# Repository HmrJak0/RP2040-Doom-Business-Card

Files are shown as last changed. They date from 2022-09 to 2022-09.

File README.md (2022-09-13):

# RP2040 Stamp Footprints and Symbols

This repo contains symbols and footprints for the RP2040 Stamp for various CAD programs.

The "KiCad" directory can be used with KiCad v6, for v5 version, see the "KiCad5" directory.

If you notice any issues with the footprints (we are mainly KiCad users), or want to port the footprint to a new program, PRs are very welcome :)

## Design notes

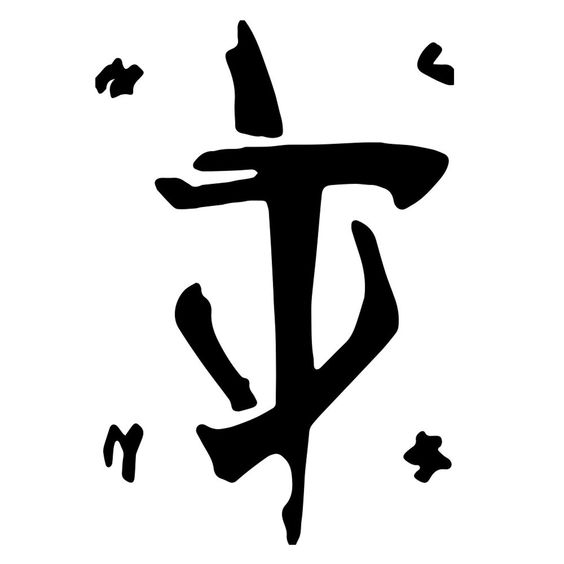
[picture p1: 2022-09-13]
Doom_Slayer_Sigil.jpg

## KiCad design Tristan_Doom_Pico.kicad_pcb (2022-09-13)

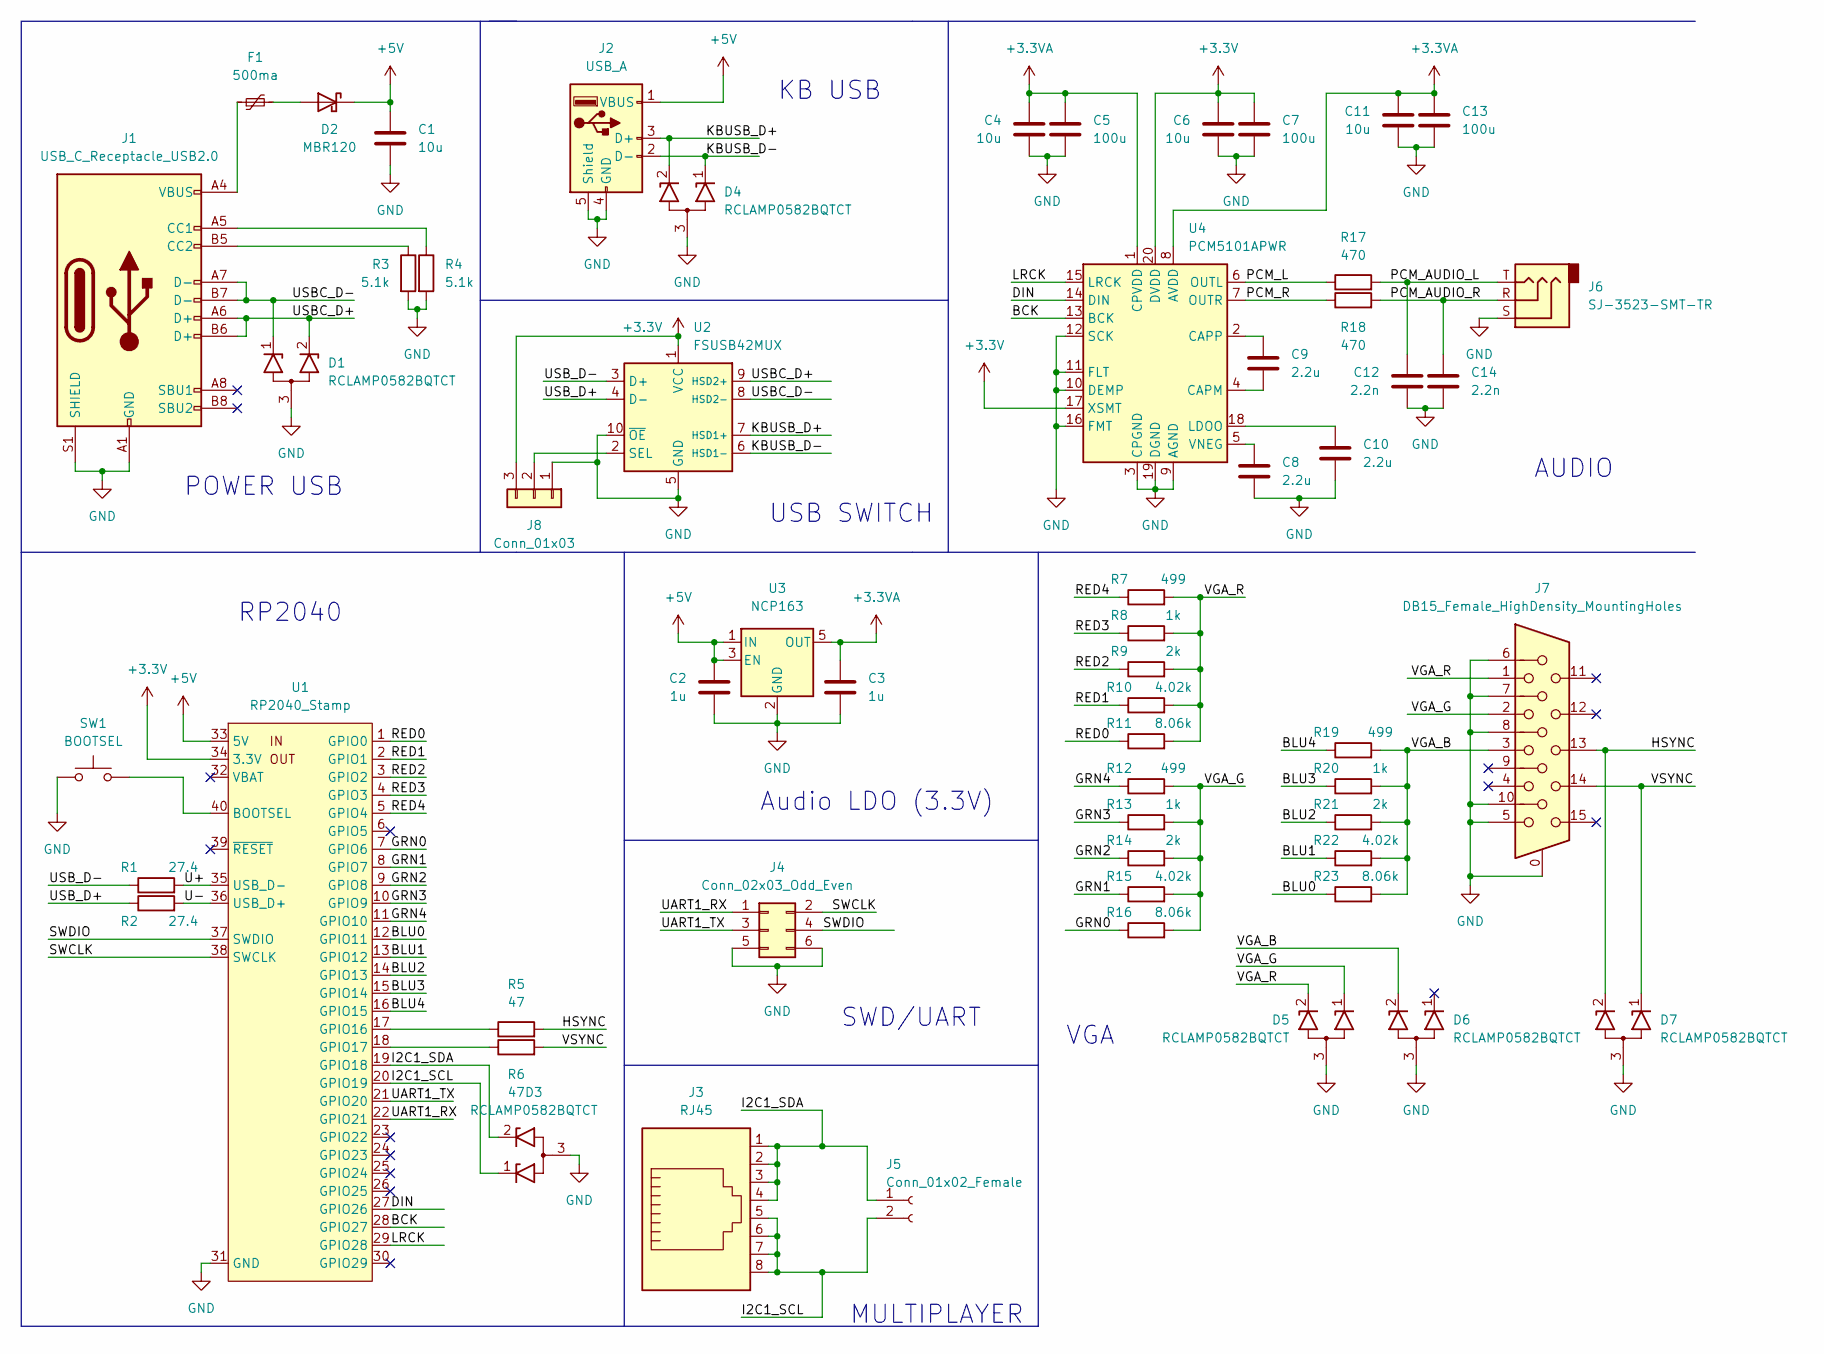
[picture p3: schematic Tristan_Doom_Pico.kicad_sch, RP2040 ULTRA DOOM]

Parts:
C1, C4, C6, C11: 10u; C_0805_2012Metric
C2, C3: 1u; C_0805_2012Metric
C5, C7, C13: 100u; C_1210_3225Metric
C8, C9, C10: 2.2u; C_0603_1608Metric
C12, C14: 2.2n; C_0603_1608Metric
D1, D3, D4, D5, D6, D7: RCLAMP0582BQTCT; TVS_RCLAMP0502B.TCT; MouserPN 947-RCLAMP0582BQTCT
D2: MBR120; D_SOD-123F
F1: 500ma; Fuse_1206_3216Metric
J1: USB_C_Receptacle_USB2.0; USB_C_Receptacle_JAE_DX07S016JA1R1500; MouserPN 656-DX07S016JA1R1500
J2: USB_A; USB_A_Stewart_SS-52100-001_Horizontal; MouserPN 530-SS-52100-001
J3: RJ45; RJ45_Amphenol_54602-x08_Horizontal; MouserPN 649-54602-908LF
J4: Conn_02x03_Odd_Even; PinHeader_2x03_P2.54mm_Vertical
J5: Conn_01x02_Female; PinHeader_1x02_P2.54mm_Vertical
J6: SJ-3523-SMT-TR; SJ3523SMTTR; Mouser Part Number 490-SJ-3523-SMT-TR
J7: DB15_Female_HighDensity_MountingHoles; L77HDE15SD1CH4RHNVGA
J8: Conn_01x03; PinHeader_1x03_P2.54mm_Vertical
R1, R2: 27.4; R_1206_3216Metric; MouserPN 71-CRCW120627R4FKTB
R3, R4: 5.1k; R_1206_3216Metric; MouserPN 71-CRCW12065K10FKEAC
R5, R6: 47; R_1206_3216Metric; MouserPN 71-CRCW120647R0FKEAC
R7, R12, R19: 499; R_1206_3216Metric; MouserPN 71-CRCW1206499RFKEAC
R8, R13, R20: 1k; R_1206_3216Metric; MouserPN 71-CRCW12061K00FKEAC
R9, R14, R21: 2k; R_1206_3216Metric; MouserPN 71-CRCW12062K00FKEAC
R10, R15, R22: 4.02k; R_1206_3216Metric; MouserPN 71-CRCW12064K02FKEAC
R11, R16, R23: 8.06k; R_1206_3216Metric; MouserPN 71-CRCW1206-8.66K-E3
R17, R18: 470; R_1206_3216Metric; MouserPN 71-CRCW1206470RFKEAC
SW1: BOOTSEL; SW_PUSH_6mm
U1: RP2040_Stamp; RP2040_Stamp_THT
U2: FSUSB42MUX; MSOP-10_3x3mm_P0.5mm; MouserPN 512-FSUSB42MUX
U3: NCP163; SOT-23-5
U4: PCM5101APWR; TSSOP-20_4.4x6.5mm_P0.65mm

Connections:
+3.3VA: C3.1, C4.1, C5.1, C11.1, C13.1, U3.5 (OUT), U4.1 (CPVDD), U4.8 (AVDD)
+3V3: C6.1, C7.1, J8.3, U1.34 (3.3V), U2.1 (VCC), U4.17 (XSMT), U4.20 (DVDD)
+5V: C1.1, C2.1, D2.1 (K), J2.1 (VBUS), U1.33 (5V), U3.1 (IN), U3.3 (EN)
/BCK: U1.28 (GPIO27), U4.13 (BCK)
/BLU0: R23.1, U1.12 (GPIO11)
/BLU1: R22.1, U1.13 (GPIO12)
/BLU2: R21.1, U1.14 (GPIO13)
/BLU3: R20.1, U1.15 (GPIO14)
/BLU4: R19.1, U1.16 (GPIO15)
/DIN: U1.27 (GPIO26), U4.14 (DIN)
/GRN0: R16.1, U1.7 (GPIO6)
/GRN1: R15.1, U1.8 (GPIO7)
/GRN2: R14.1, U1.9 (GPIO8)
/GRN3: R13.1, U1.10 (GPIO9)
/GRN4: R12.1, U1.11 (GPIO10)
/HSYNC: D7.2 (K2), J7.13, R5.2
/I2C1_SCL: D3.1 (K1), J3.5, J3.6, J3.7, J3.8, J5.2, U1.20 (GPIO19)
/I2C1_SDA: D3.2 (K2), J3.1, J3.2, J3.3, J3.4, J5.1, U1.19 (GPIO18)
/KBUSB_D+: D4.2 (K2), J2.3 (D+), U2.7 (HSD1+)
/KBUSB_D-: D4.1 (K1), J2.2 (D-), U2.6 (HSD1-)
/LRCK: U1.29 (GPIO28), U4.15 (LRCK)
/PCM_AUDIO_L: C12.1, J6.T, R17.2
/PCM_AUDIO_R: C14.1, J6.R, R18.2
/PCM_L: R17.1, U4.6 (OUTL)
/PCM_R: R18.1, U4.7 (OUTR)
/RED0: R11.1, U1.1 (GPIO0)
/RED1: R10.1, U1.2 (GPIO1)
/RED2: R9.1, U1.3 (GPIO2)
/RED3: R8.1, U1.4 (GPIO3)
/RED4: R7.1, U1.5 (GPIO4)
/SWCLK: J4.2, U1.38 (SWCLK)
/SWDIO: J4.4, U1.37 (SWDIO)
/U+: R1.2, U1.35 (USB_D-)
/U-: R2.2, U1.36 (USB_D+)
/UART1_RX: J4.1, U1.22 (GPIO21)
/UART1_TX: J4.3, U1.21 (GPIO20)
/USBC_D+: D1.2 (K2), J1.A6 (D+), J1.B6 (D+), U2.9 (HSD2+)
/USBC_D-: D1.1 (K1), J1.A7 (D-), J1.B7 (D-), U2.8 (HSD2-)
/USB_D+: R2.1, U2.4 (D-)
/USB_D-: R1.1, U2.3 (D+)
/VGA_B: D6.2 (K2), J7.3, R19.2, R20.2, R21.2, R22.2, R23.2
/VGA_G: D5.1 (K1), J7.2, R12.2, R13.2, R14.2, R15.2, R16.2
/VGA_R: D5.2 (K2), J7.1, R7.2, R8.2, R9.2, R10.2, R11.2
/VSYNC: D7.1 (K1), J7.14, R6.2
GND: C1.2, C2.2, C3.2, C4.2, C5.2, C6.2, C7.2, C8.2, C10.2, C11.2, C12.2, C13.2, C14.2, D1.3 (A), D3.3 (A), D4.3 (A), D5.3 (A), D6.3 (A), D7.3 (A), J1.A1 (GND), J1.A12 (GND), J1.B1 (GND), J1.B12 (GND), J1.S1 (SHIELD), J2.4 (GND), J2.5 (Shield), J4.5, J4.6, J6.S, J7.0, J7.5, J7.6, J7.7, J7.8, J7.10, J8.1, R3.2, R4.2, SW1.1, U1.31 (GND), U2.5 (GND), U2.10 (~OE), U3.2 (GND), U4.3 (CPGND), U4.9 (AGND), U4.10 (DEMP), U4.11 (FLT), U4.12 (SCK), U4.16 (FMT), U4.19 (DGND)
unnamed: C8.1, U4.5 (VNEG)
unnamed: C9.1, U4.2 (CAPP)
unnamed: C9.2, U4.4 (CAPM)
unnamed: C10.1, U4.18 (LDOO)
unnamed: D2.2 (A), F1.2
unnamed: F1.1, J1.A4 (VBUS), J1.A9 (VBUS), J1.B4 (VBUS), J1.B9 (VBUS)
unnamed: J1.A5 (CC1), R4.1
unnamed: J1.B5 (CC2), R3.1
unnamed: J8.2, U2.2 (SEL)
unnamed: R5.1, U1.17 (GPIO16)
unnamed: R6.1, U1.18 (GPIO17)
unnamed: SW1.2, U1.40 (BOOTSEL)

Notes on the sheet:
VGA
Audio LDO (3.3V)
SWD/UART
MULTIPLAYER
USB SWITCH
POWER USB
AUDIO
RP2040
KB USB

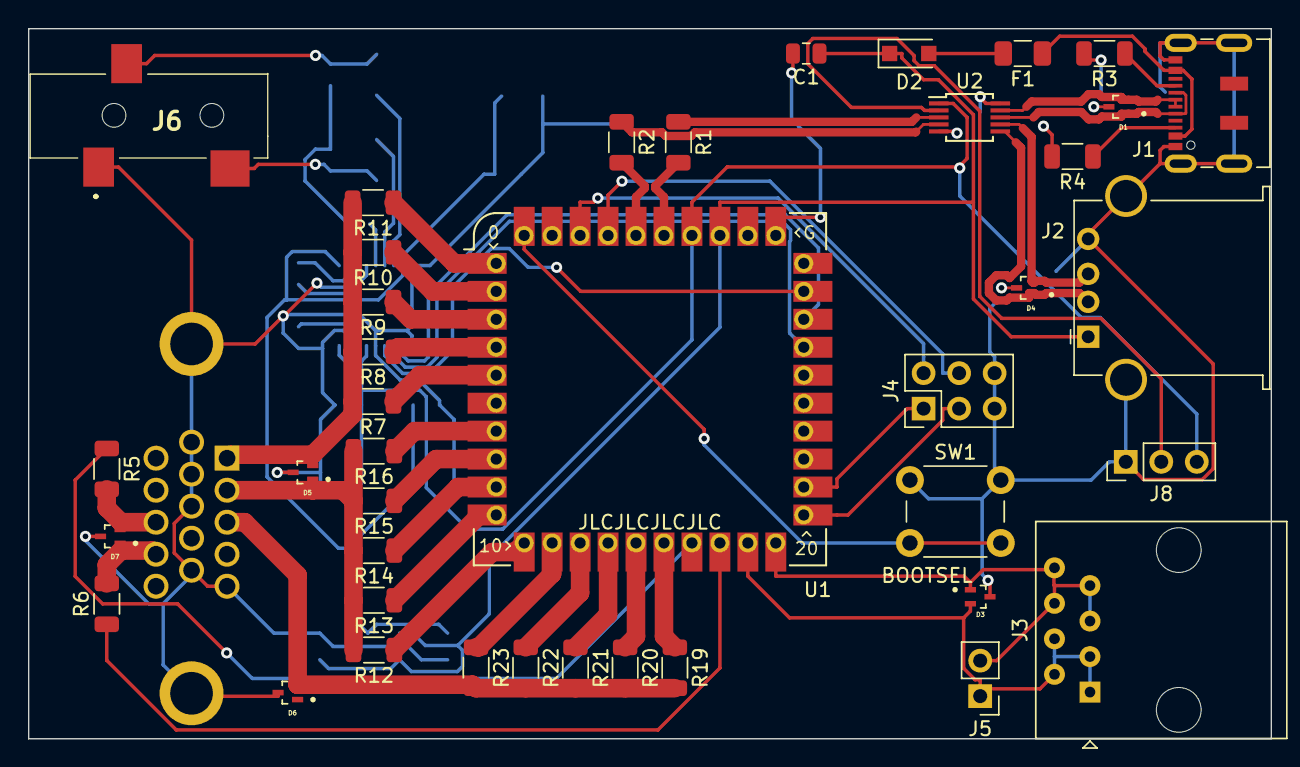
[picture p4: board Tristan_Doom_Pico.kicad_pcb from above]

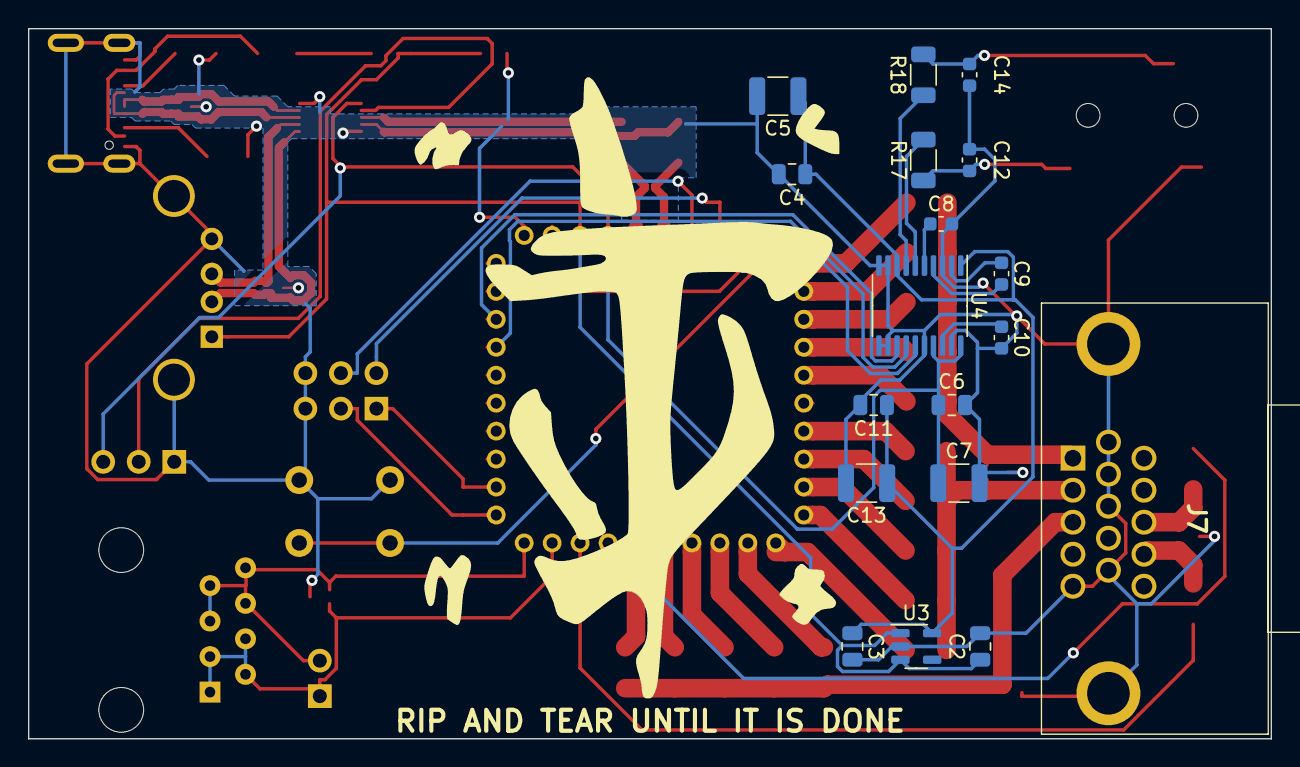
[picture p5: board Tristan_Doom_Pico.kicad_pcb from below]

Board: 2 copper layers, 88.9 x 50.8 mm, 58 parts (18 on the bottom side), 57 nets.

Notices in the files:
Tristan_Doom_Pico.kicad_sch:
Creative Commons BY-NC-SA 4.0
